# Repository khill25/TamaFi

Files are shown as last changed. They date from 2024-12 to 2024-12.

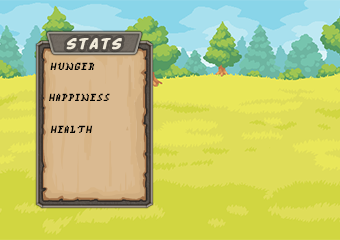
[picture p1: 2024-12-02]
Ui Graphics/pic/backgroundImage.png

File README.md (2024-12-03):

<div align="center">

  
  
  <h1> TamaFi </h1>
  <p> TamaFi is an open-source, WiFi-enabled virtual pet </p>

<!-- Badges -->




<h4>
    <a href="https://twitter.com/techcifer">TWITTER</a>
  <span> · </span>
    <a href="https://www.instagram.com/cifertech/">INSTAGRAM</a>
  <span> · </span>
    <a href="https://www.youtube.com/@techcifer">YOUTUBE</a>
  <span> · </span>
    <a href="https://cifertech.net/">WEBSITE</a>
  </h4>
</div>

<br />

<div>&nbsp;</div>

## 📖 Explore the Full Documentation

Ready to dive deeper into TamaFi's details? Discover the full story, in-depth tutorials, and all the exciting features in our comprehensive [documentation](https://cifertech.net/tamafi-reviving-the-classic-virtual-pet-with-a-tech-twist/). Click the link and explore further!
  
<div>&nbsp;</div>

<!-- About the Project -->
## :star2: About the Project
TamaFi is a modern reimagining of the classic Tamagotchi, aiming to blend nostalgia with modern technology. Built with an ESP32 microcontroller and a vibrant TFT LCD, TamaFi offers a unique twist: feeding your virtual pet through Wi-Fi scanning.

Why TamaFi?
- Classic Tamagotchis lacked vibrant graphics, backlighting, and modern interactions.
- TamaFi fills this gap by offering an enhanced virtual pet experience with open-source versatility.

<div align="center"> 
  
</div>

<div>&nbsp;</div>

<h2>🛠 Functionality Status and Reliability</h2>

TamaFi is a work-in-progress and has room for improvement. While it’s functional and exciting to use, there’s always room to make it better, more reliable, and feature-rich. Whether it’s optimizing the code, enhancing the design, or suggesting new features, your contributions are highly welcomed!

<table>
  <thead>
    <tr>
      <th>Feature</th>
      <th>Status</th>
      <th>Details</th>
    </tr>
  </thead>
  <tbody>
    <tr>
      <td>Pet Animation</td>
      <td>⚠ Stable</td>
      <td>Includes hatching, random, and stat-based animations.</td>
    </tr>
    <tr>
      <td>Stat Management</td>
      <td>⚠ Stable</td>
      <td>Hunger, happiness, and hygiene stats are tracked and updated.</td>
    </tr>
    <tr>
      <td>Wi-Fi Feeding</td>
      <td>🚧 In Progress</td>
      <td>Detects nearby networks and feeds the pet.</td>
    </tr>
    <tr>
      <td>TFT LCD Display</td>
      <td>✅ Reliable</td>
      <td>Displays sprites, stats, and animations with smooth transitions.</td>
    </tr>
    <tr>
      <td>Button Inputs</td>
      <td>⚠ Stable</td>
      <td>Three microswitches handle user interaction.</td>
    </tr>
    <tr>
      <td>PCB Design</td>
      <td>✅ Verified</td>
      <td>Tested for compatibility and efficient layout.</td>
    </tr>
    <tr>
      <td>RGB LED and Buzzer Integration</td>
      <td>🚧 In Progress</td>
      <td>Planned for the next release.</td>
    </tr>
  </tbody>
</table>

<div>&nbsp;</div>

<!-- Features -->
### 🎯 Features

**Hardware:**

- ESP32-U4 microcontroller
- TFT LCD (ST7789) with vibrant visuals
- WS2812 RGB LED for colorful effects
- Buzzer for sound alerts
- TP4056 charging module with USB-C
- LF33 voltage regulator

**Software:**

- Custom animations for pets and stats
- WiFi-based feeding system
- Interactive buttons for actions
- Egg-hatching and pet-death animations
- Open-source and easily customizable

<div>&nbsp;</div>

<!-- License -->
## :warning: License

Distributed under the MIT License. See LICENSE.txt for more information.

<div>&nbsp;</div>

<!-- Contact -->
## :handshake: Contact

▶ Support me on Patreon [patreon.com/cifertech](https://www.patreon.com/cifertech)

CiferTech - [@twitter](https://twitter.com/techcifer) - CiferTech@gmali.com

Project Link: [https://github.com/cifertech/TamaFi](https://github.com/cifertech/TamaFi)

<div>&nbsp;</div>

<!-- Acknowledgments -->
## :gem: Acknowledgements 

**The libraries and projects listed below are used in this software:**
 - [Mecha-Stone Golem](https://darkpixel-kronovi.itch.io/mecha-golem-free)
 - [Fantasy Wooden GUI](https://kanekizlf.itch.io/fantasy-wooden-gui-free)
 - [MyPixelWorld](https://scarloxy.itch.io/mpwsp01)
 - [Transparent Sprites](https://github.com/VolosR/SpritesTuT)

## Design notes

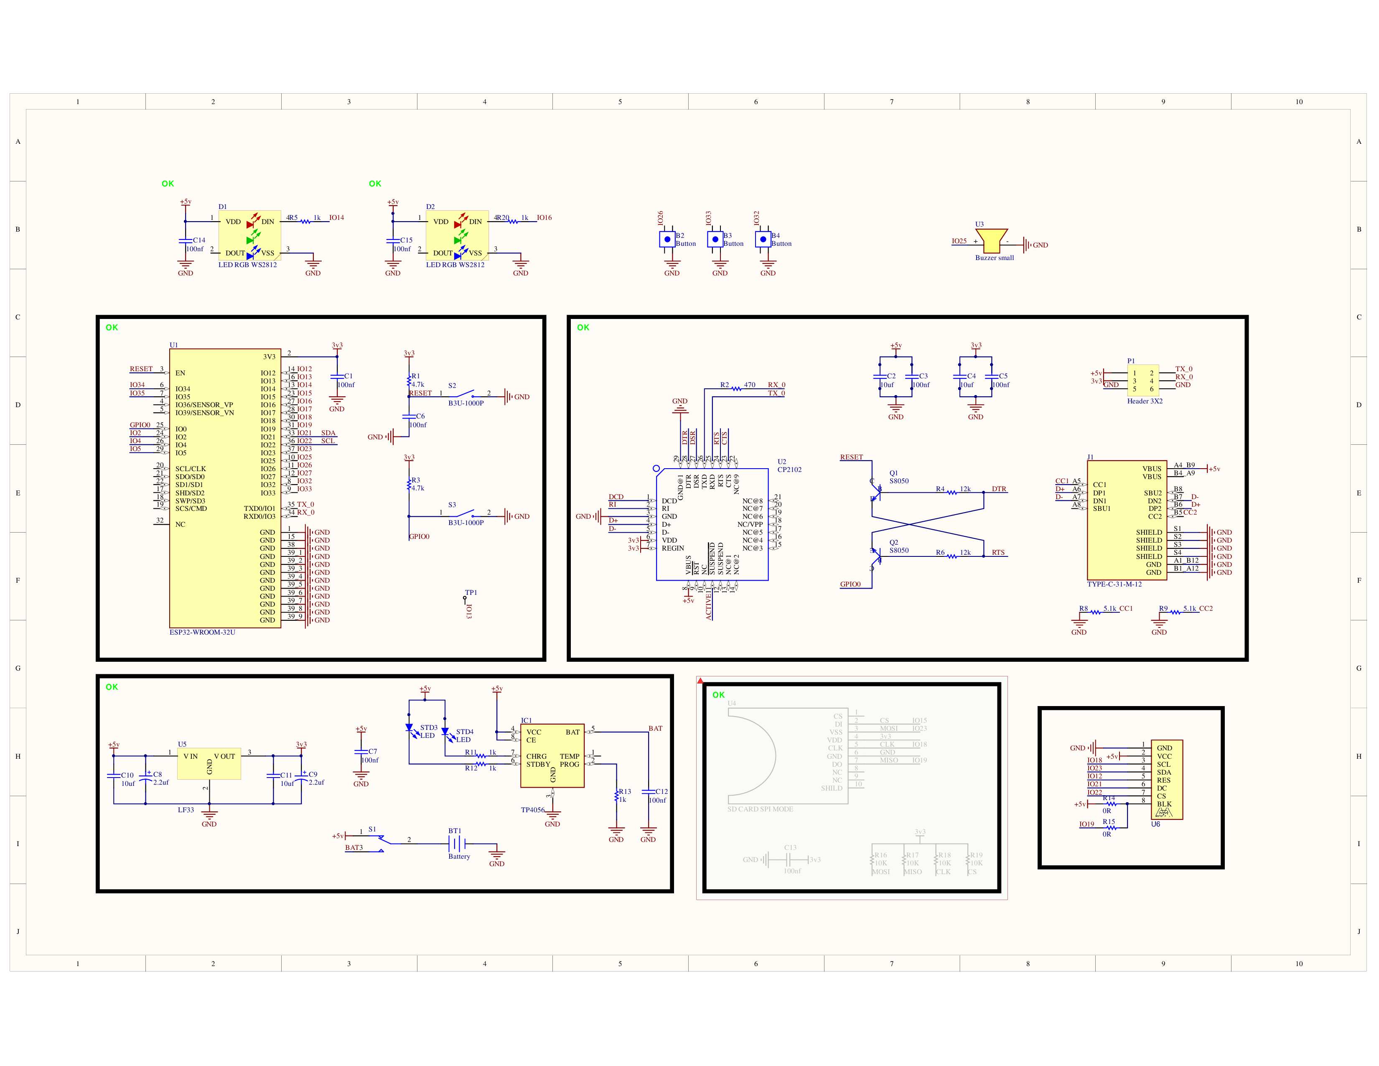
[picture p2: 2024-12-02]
Schematic/schematic.jpg

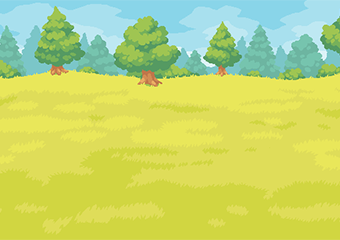
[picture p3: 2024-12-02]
Ui Graphics/pic/backgroundImage1.png

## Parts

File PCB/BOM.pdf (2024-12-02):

Comment | Description | Designator | Footprint | LibRef | Quantity
Button | PUSH BUTTON | B2, B3, B4 | PUSH BUTTON 4 PIN SMD 5 | PUSH BUTTON 4 PIN | 3
Battery | | BT1 | Bat | Battery | 1
100nf | Capacitor | C1, C3, C5, C6, C7, C12, C14, C15 | CAP0805 | CAP SMD | 8
10uf | Capacitor | C2, C4 | CAP0805 | CAP SMD | 2
Capacitor Tantalum SMD | Capacitor Tantalum SMD | C8, C9 | Tan 1206 (3216X18L) Size A | Capacitor Tantalum SMD | 2
10uf | Capacitor | C10, C11 | CAP 1206 (3216X15L) | CAP SMD | 2
LED RGB WS2812 | LED | D1, D2 | LED 5050 WS2812B | LED RGB WS2812 | 2
TP4056 | Complete single cell Li-Ion battery with a constant current / constant voltage linear charger | IC1 | SOP-8 | TP4056 | 1
TYPE-C-31-M-12 | USB Connectors 24 Receptacle 1 8.94*7.3mm RoHS | J1 | HRO_TYPE-C-31-M-12 | TYPE-C-31-M-12 | 1
Header 3X2 | Header, 3-Pin, Dual row | P1 | HDR2X3 | Header 3X2 | 1
S8050 | Bipolar (BJT) Transistor NPN 25 V 500 mA 150MHz 300 mW Surface Mount SOT-23 | Q1, Q2 | SOT-23 | SMD-TRANSISTORS-NPN-25V-500MW(SOT-23) | 2
4.7k | RESISTOR | R1, R3 | RES 0805 | RES | 2
470 | RESISTOR | R2 | RES 0805 | RES | 1
12k | RESISTOR | R4, R6 | RES 0805 | RES | 2
1k | RESISTOR | R5, R20 | RES 0805 (2012X06L) | RES | 2
5.1k | RESISTOR | R8, R9 | RES 0805 | RES | 2
1k | RESISTOR | R11, R12, R13 | RES 0805 | RES | 3
0R | RESISTOR | R14, R15 | RES 0805 | RES | 2
1437566-3 | | S1 | Subminiator SPDT switch | Subminiator SPDT switch | 1
B3U-1000P | Switch Tactile N.O. SPST Round Button Gull Wing 0.05A 12VDC 1.5N SMD Embossed T/R | S2, S3 | SW_B3U-1000P | B3U-1000P | 2
LED | LED | STD3, STD4 | L0805 | LED | 2
Test Point | Test Point | TP1 | Test Point SMD | Test Point | 1
ESP32-WROOM-32U | Bluetooth, WiFi 802.11b/g/n, Bluetooth v4.2 +EDR, Class 1, 2 and 3 Transceiver Module 2.4GHz ~ 2.5GHz Antenna Not Included, U.FL Surface Mount | U1 | XCVR_ESP32-WROOM-32U | ESP32-WROOM-32U | 1
CP2102 | USB Bridge, USB to UART USB 2.0 UART Interface 28-QFN _5x5_ | U2 | QFN28G_0.5-5X5MM | INTERFACE-CP2102-GMR(QFN28) | 1
Buzzer small | 5-12v small buzzer (12mm) | U3 | BUZZER | Buzzer | 1
LF33 | 3.3V VOLTAGE REGULATOR | U5 | D-PACK | LF33 | 1
LCDTFT_1.69IN | LCD TFT Color, 1.69", 240X280, ST7789V Driver | U6 | LCDTFT_1.69IN_ST7 789V_MOD | LCDTFT_1.69IN_ST7 789V_MOD | 1

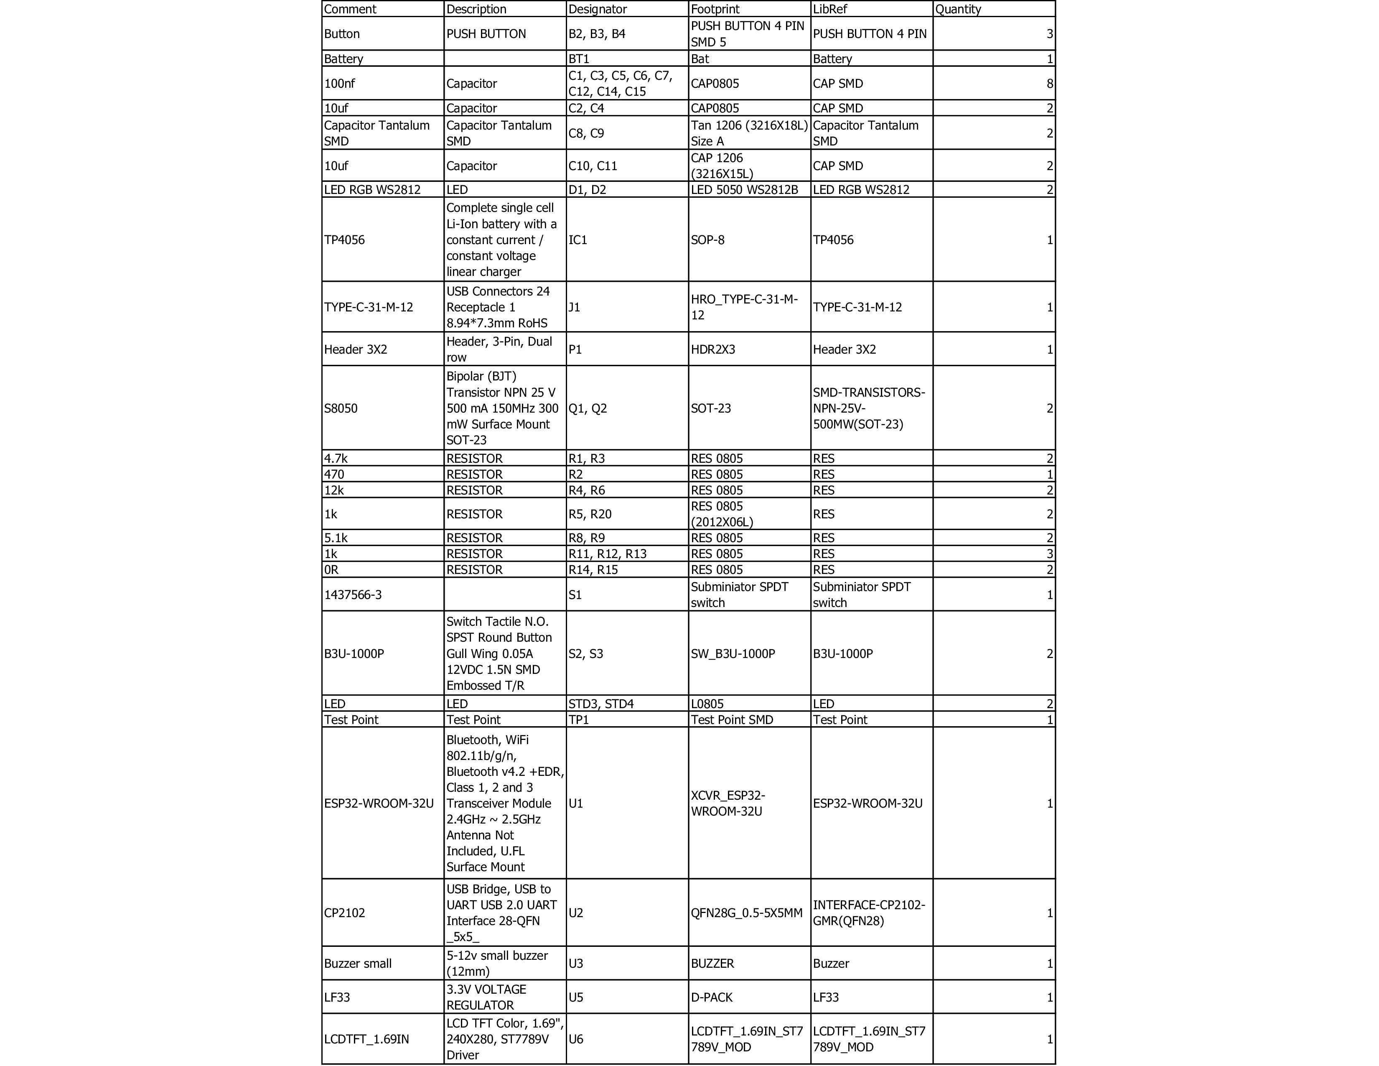
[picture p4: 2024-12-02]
Schematic/components.jpg

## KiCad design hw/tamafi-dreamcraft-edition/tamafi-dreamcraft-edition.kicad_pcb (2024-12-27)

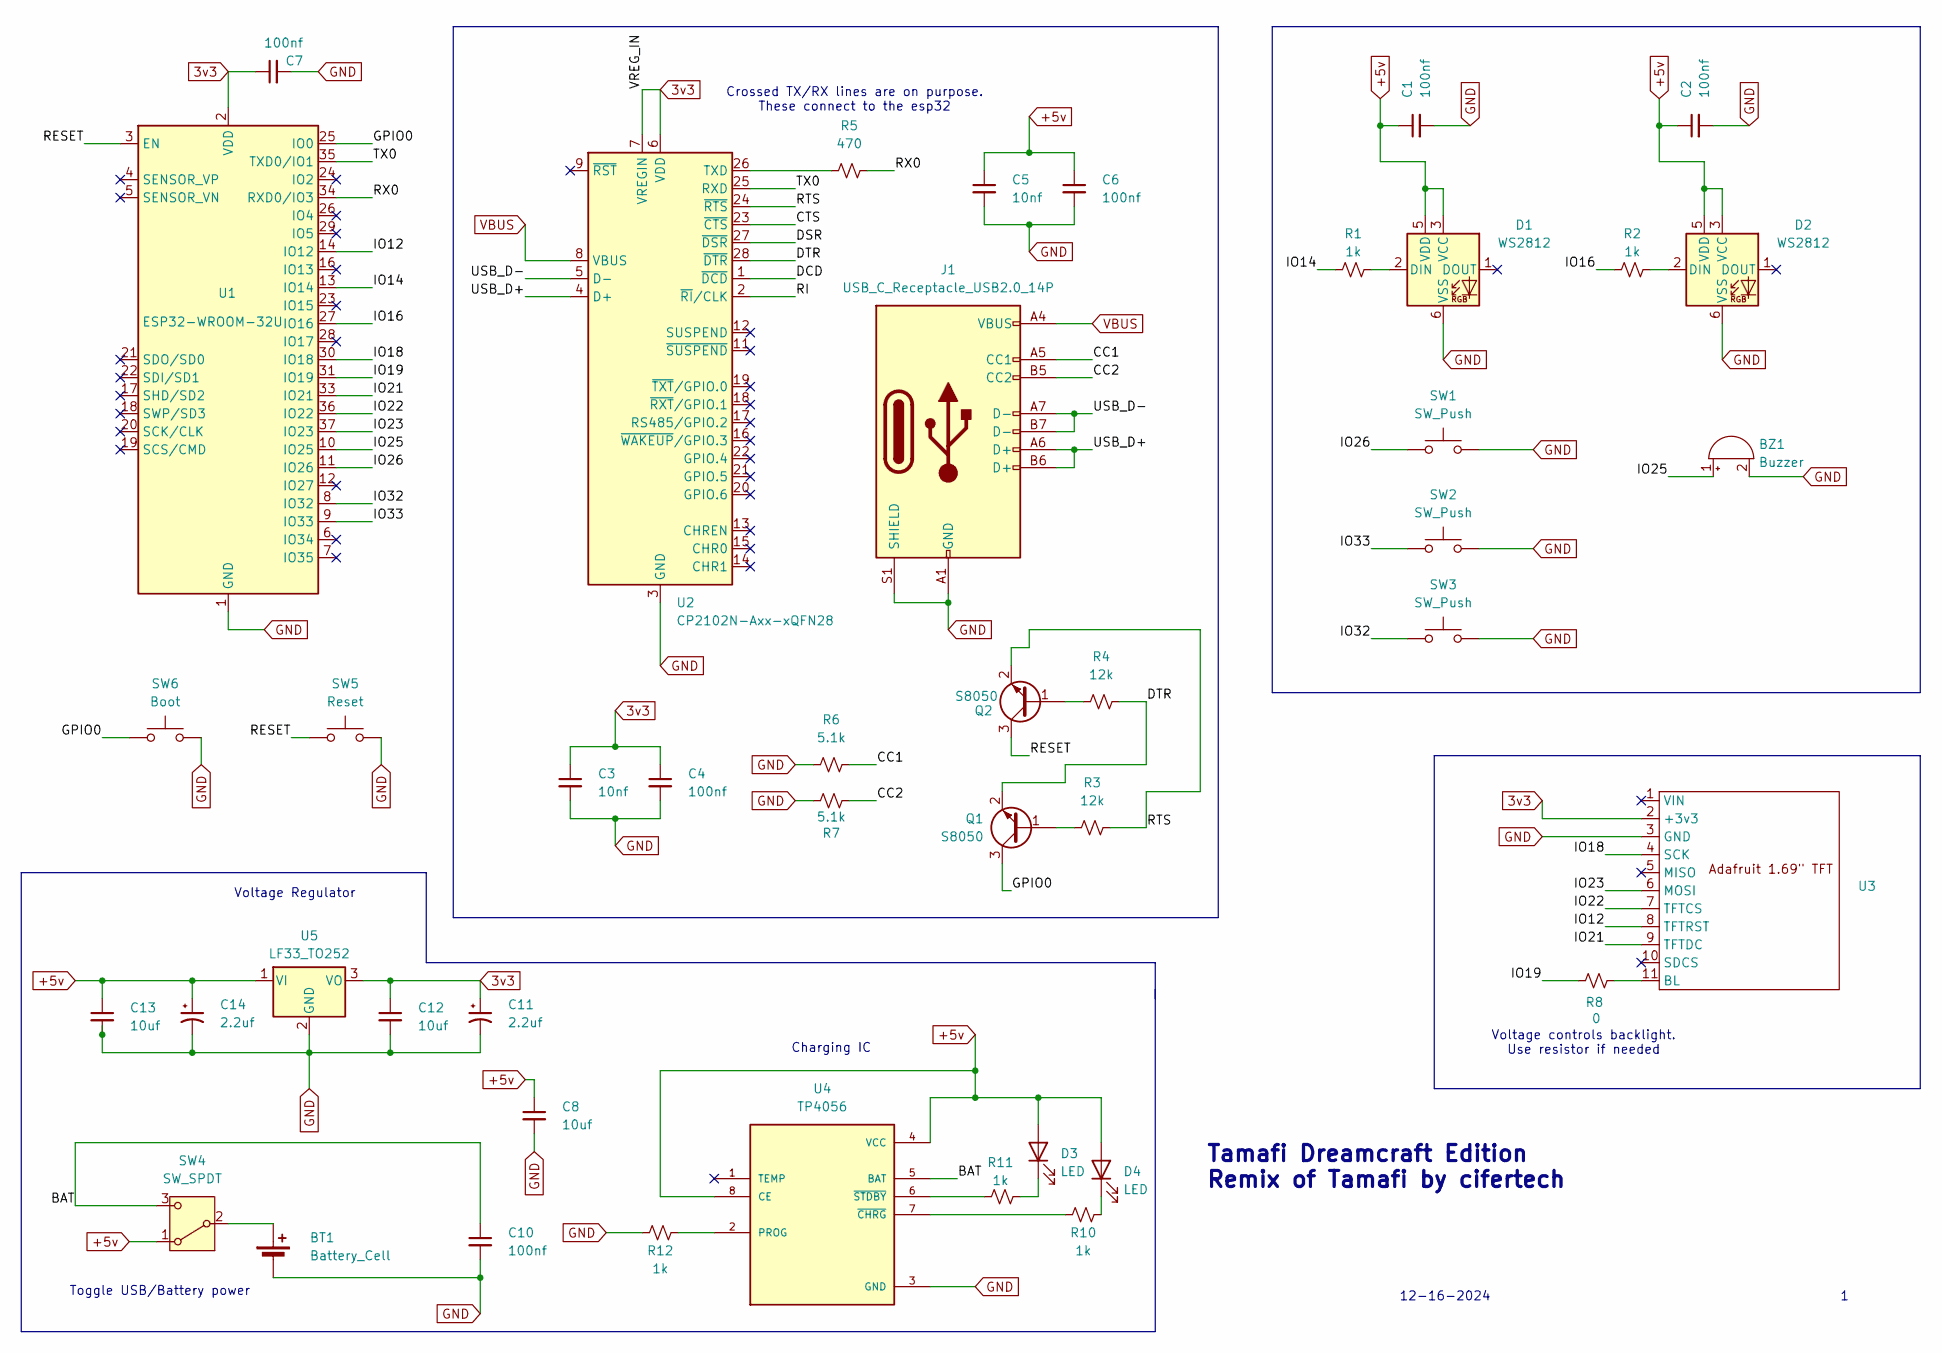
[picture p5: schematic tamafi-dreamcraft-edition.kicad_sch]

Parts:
BT1: Battery_Cell; JST_PH_B2B-PH-K_1x02_P2.00mm_Vertical
BZ1: Buzzer; Buzzer_12x9.5RM7.6
C1, C2, C4, C6, C7, C10: 100nf; C_0805_2012Metric
C3, C5: 10nf; C_0805_2012Metric
C8, C12, C13: 10uf; C_0805_2012Metric
C11, C14: 2.2uf; C_0805_2012Metric
D1, D2: WS2812; LED_WS2812_PLCC6_5.0x5.0mm_P1.6mm
D3, D4: LED; LED_0805_2012Metric_Pad1.15x1.40mm_HandSolder
J1: USB_C_Receptacle_USB2.0_14P; USB_C_Receptacle_HRO_TYPE-C-31-M-12
Q1, Q2: S8050; SOT-23
R1, R2, R10, R11, R12: 1k; R_0805_2012Metric
R3, R4: 12k; R_0805_2012Metric
R5: 470; R_0805_2012Metric
R6, R7: 5.1k; R_0805_2012Metric
R8: 0; R_0805_2012Metric
SW1, SW2, SW3: SW_Push; SW_SPST_B3S-1000
SW4: SW_SPDT; SW_Slide-03_Wuerth-WS-SLTV_10x2.5x6.4_P2.54mm
SW5: Reset; SW_SPST_FSMSM
SW6: Boot; SW_SPST_FSMSM
U1: ESP32-WROOM-32U
U2: CP2102N-Axx-xQFN28; QFN-28-1EP_5x5mm_P0.5mm_EP3.35x3.35mm
U3: Adafruit 1.69in 280x240 TFT
U4: TP4056; SOP-8_3.9x4.9mm_P1.27mm
U5: LF33_TO252; TO-252-2

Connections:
3v3: C3.1, C4.1, C7.1, C11.1, C12.1, U1.2 (VDD), U2.6 (VDD), U2.7 (VREGIN), U3.2 (+3v3), U5.3 (VO)
+5v: C1.1, C2.1, C5.1, C6.1, C8.1, C13.1, C14.1, D1.3 (VCC), D1.5 (VDD), D2.3 (VCC), D2.5 (VDD), D3.2 (A), D4.2 (A), SW4.1 (A), U4.4 (VCC), U4.8 (CE), U5.1 (VI)
/BAT: C10.1, SW4.3 (C), U4.5 (BAT)
/CC1: J1.A5 (CC1), R6.2
/CC2: J1.B5 (CC2), R7.2
/CTS: U2.23 (~CTS)
/DCD: U2.1 (~DCD)
/DSR: U2.27 (~DSR)
/DTR: Q1.2 (E), R4.2, U2.28 (~DTR)
/GPIO0: Q1.3 (C), SW6.1, U1.25 (IO0)
/IO12: U1.14 (IO12), U3.8 (TFTRST)
/IO14: R1.2, U1.13 (IO14)
/IO16: R2.2, U1.27 (IO16)
/IO18: U1.30 (IO18), U3.4 (SCK)
/IO19: R8.2, U1.31 (IO19)
/IO21: U1.33 (IO21), U3.9 (TFTDC)
/IO22: U1.36 (IO22), U3.7 (TFTCS)
/IO23: U1.37 (IO23), U3.6 (MOSI)
/IO25: BZ1.1 (+), U1.10 (IO25)
/IO26: SW1.1, U1.11 (IO26)
/IO32: SW3.1, U1.8 (IO32)
/IO33: SW2.1, U1.9 (IO33)
/RESET: Q2.3 (C), SW5.1, U1.3 (EN)
/RI: U2.2 (~RI/CLK)
/RTS: Q2.2 (E), R3.2, U2.24 (~RTS)
/RX0: R5.2, U1.34 (RXD0/IO3)
/TX0: U1.35 (TXD0/IO1), U2.25 (RXD)
/USB_D+: J1.A6 (D+), J1.B6 (D+), U2.4 (D+)
/USB_D-: J1.A7 (D-), J1.B7 (D-), U2.5 (D-)
GND: BT1.2 (-), BZ1.2 (-), C1.2, C2.2, C3.2, C4.2, C5.2, C6.2, C7.2, C8.2, C10.2, C11.2, C12.2, C13.2, C14.2, D1.6 (VSS), D2.6 (VSS), J1.A1 (GND), J1.A12 (GND), J1.B1 (GND), J1.B12 (GND), J1.S1 (SHIELD), R6.1, R7.1, R12.1, SW1.2, SW2.2, SW3.2, SW5.2, SW6.2, U1.1 (GND), U1.15 (GND), U1.38 (GND), U1.39 (GND), U2.3 (GND), U2.29 (GND), U3.3 (GND), U4.3 (GND), U5.2 (GND)
unnamed: BT1.1 (+), SW4.2 (B)
unnamed: D1.2 (DIN), R1.1
unnamed: D2.2 (DIN), R2.1
unnamed: D3.1 (K), R11.1
unnamed: D4.1 (K), R10.2
unnamed: Q1.1 (B), R3.1
unnamed: Q2.1 (B), R4.1
unnamed: R5.1, U2.26 (TXD)
unnamed: R8.1, U3.11 (BL)
unnamed: R12.2, U4.2 (PROG)
unnamed: R10.1, U4.7 (~CHRG)
unnamed: R11.2, U4.6 (~STDBY)
VBUS: J1.A4 (VBUS), J1.A9 (VBUS), J1.B4 (VBUS), J1.B9 (VBUS), U2.8 (VBUS)

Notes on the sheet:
12-16-2024
Charging IC
Voltage Regulator
Toggle USB/Battery power
Crossed TX/RX lines are on purpose. These connect to the esp32
Voltage controls backlight. Use resistor if needed
Tamafi Dreamcraft Edition Remix of Tamafi by cifertech

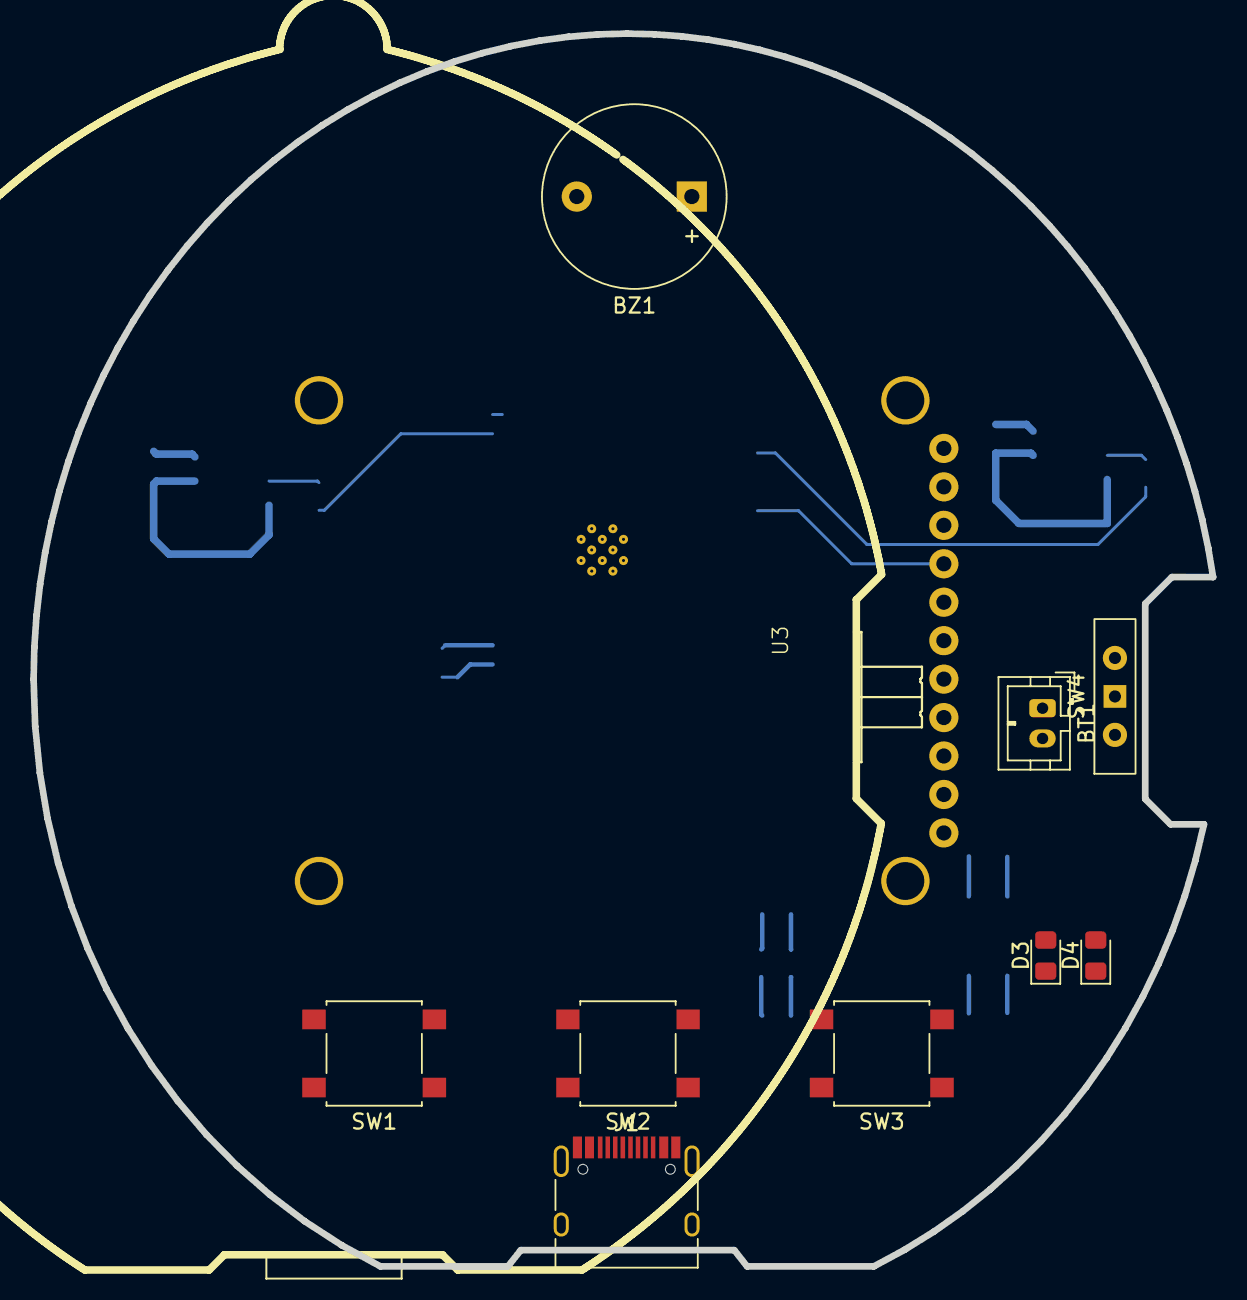
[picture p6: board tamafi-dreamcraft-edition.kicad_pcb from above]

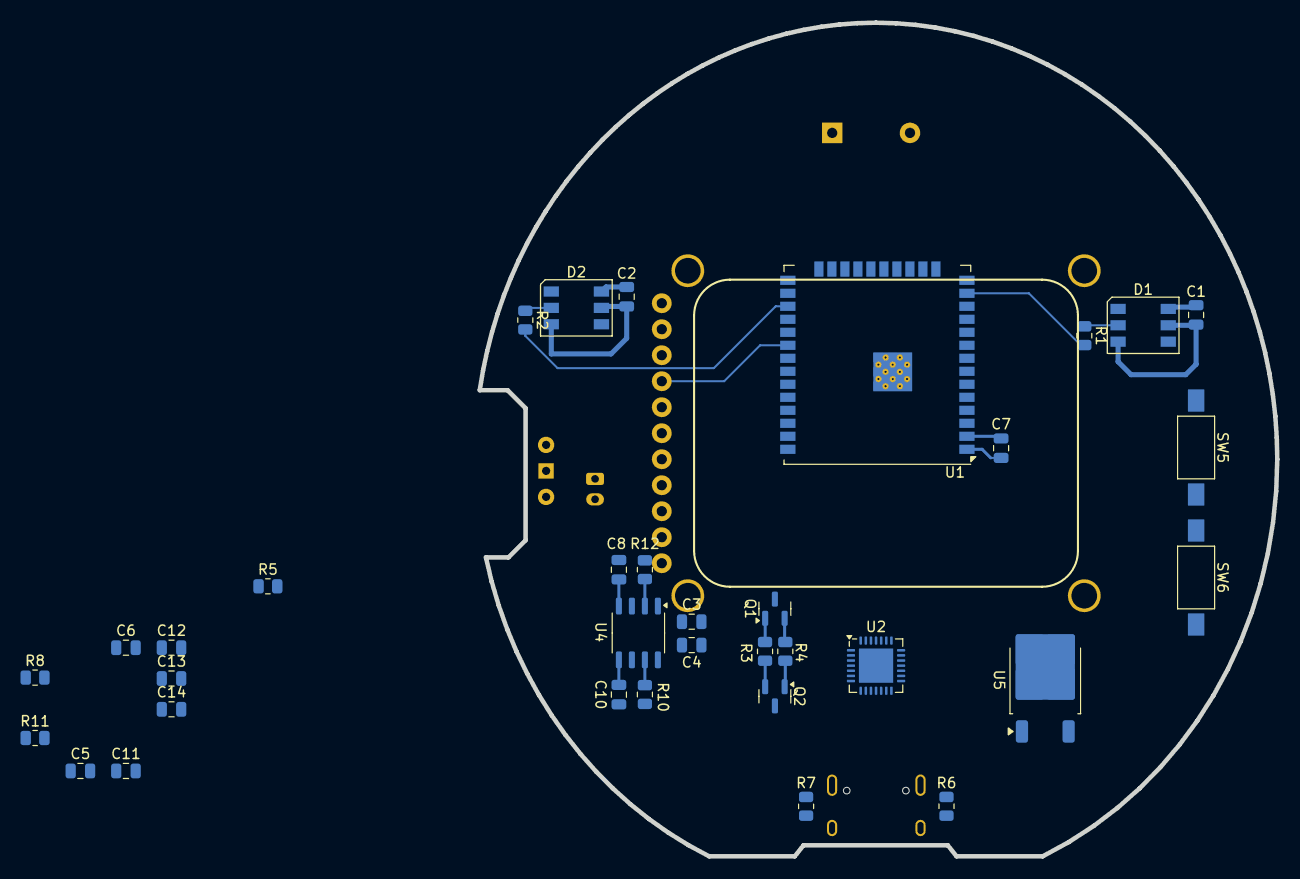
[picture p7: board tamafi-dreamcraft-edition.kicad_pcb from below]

Board: 2 copper layers, 77.9 x 81.4 mm, 44 parts (34 on the bottom side), 39 nets.

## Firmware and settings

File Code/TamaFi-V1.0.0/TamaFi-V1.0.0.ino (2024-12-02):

#include <TFT_eSPI.h>

//#include "pet.h"    
//#include "eyepet.h"  
#include "StoneGolem.h"

#include "egg_hatch.h"
   
#include "effect.h" 
#include "background.h"  

TFT_eSPI tft = TFT_eSPI(); 

TFT_eSprite arrowSprite = TFT_eSprite(&tft); 
TFT_eSprite background = TFT_eSprite(&tft);

TFT_eSprite hatchingSprite = TFT_eSprite(&tft);

bool firstStart = true; // Ensure the animation only runs once

unsigned long lastUpdateTime = 0; // Track the last time logic was updated

// GPIO Button Pins
const int feedButton = 26;
const int playButton = 33;
const int healButton = 32;

// Tamagotchi stats
int hunger = 50;   // 0-100 scale
int happiness = 50; // 0-100 scale
int health = 50;   // 0-100 scale

// Timing variables
unsigned long hungerTimer = 0;
unsigned long happinessTimer = 0;
unsigned long healthTimer = 0;

// Animation frames
int currentFrame = 0; // Animation frame index
const int animationDelay = 200; // Delay between frames
unsigned long lastAnimationTime = 0;

bool hungerEffectActive = false; // Tracks if the hunger animation is active
unsigned long hungerEffectStartTime = 0; // Tracks when the effect starts
int hungerEffectFrame = 0; // Tracks the current frame of the effect


void setup() {
  tft.init();
  tft.setRotation(3);
  tft.setSwapBytes(true);

  background.setColorDepth(8);
  background.createSprite(320, 340);
  background.setSwapBytes(true);

  arrowSprite.createSprite(115, 110);

  // Initialize hatching sprite
  //hatchingSprite.setColorDepth(16);
  hatchingSprite.createSprite(115, 110);
  hatchingSprite.setSwapBytes(false);

  // Initialize the display
  background.fillSprite(TFT_BLACK);
  background.pushSprite(0, 0);



  // Set up buttons as inputs
  pinMode(feedButton, INPUT_PULLUP);
  pinMode(playButton, INPUT_PULLUP);
  pinMode(healButton, INPUT_PULLUP);
}

void loop() {
  unsigned long currentTime = millis();

  // Check button press (assuming hunger button is GPIO 26)
  if (digitalRead(26) == LOW) { // Button is pressed
    if (!hungerEffectActive) {
      hungerEffectActive = true;
      hungerEffectStartTime = millis(); // Record start time
      hungerEffectFrame = 0;            // Reset animation frame
    }
  }

  // Handle hunger effect animation
  if (hungerEffectActive) {
    unsigned long currentTime = millis();
    if (currentTime - hungerEffectStartTime > 100) { // Frame duration: 100ms
      hungerEffectStartTime = currentTime; // Reset frame time
      hungerEffectFrame++;                 // Advance to next frame

      if (hungerEffectFrame >= 4) { // End animation after 4 frames
        hungerEffectActive = false;
      }
    }
  }

  // Render the frame
  renderFrame();

  // Check button presses
  if (digitalRead(feedButton) == LOW) {
    feedPet();
    delay(200); // Debounce delay
  }
  if (digitalRead(playButton) == LOW) {
    playWithPet();
    delay(200); // Debounce delay
  }
  if (digitalRead(healButton) == LOW) {
    healPet();
    delay(200); // Debounce delay
  }

  // Update Tamagotchi stats every 5 seconds
  if (currentTime - hungerTimer >= 5000) {
    hunger = max(0, hunger - 5); // Decrease hunger
    hungerTimer = currentTime;
  }
  if (currentTime - happinessTimer >= 7000) {
    happiness = max(0, happiness - 3); // Decrease happiness
    happinessTimer = currentTime;
  }
  if (currentTime - healthTimer >= 10000) {
    health = max(0, health - 1); // Decrease health
    healthTimer = currentTime;
  }

  // Animation Logic
  if (currentTime - lastAnimationTime >= animationDelay) {
    currentFrame = (currentFrame + 1) % 4; // Loop through frames 0-3
    lastAnimationTime = currentTime;

    // Render the current frame
    renderFrame();
  }

  // Check if stats fall too low
  if (hunger <= 0 && happiness <= 0 && health <= 0) {
    displayGameOver();
    //return; // End the loop
  }

  if (firstStart) {
    playHatchingAnimationLoop(); // Run the hatching animation
    firstStart = false;          // Mark animation as done
    hatchingSprite.deleteSprite(); // Free memory after animation
  }
}

void playHatchingAnimationLoop() {
  int delayTime = 300; // Delay between frames

    // Frame 1
    background.pushImage(0, 0, 340, 240, backgroundImage2);
    hatchingSprite.pushImage(0, 0, 115, 110, egg_hatch_1);
    hatchingSprite.pushToSprite(&background, 100, 90, TFT_WHITE); // Adjust position
    background.pushSprite(0, 0);
    delay(delayTime);

    // Frame 2
    background.pushImage(0, 0, 340, 240, backgroundImage2);
    hatchingSprite.pushImage(0, 0, 115, 110, egg_hatch_2);
    hatchingSprite.pushToSprite(&background, 100, 90, TFT_WHITE);
    background.pushSprite(0, 0);
    delay(delayTime);

    // Frame 3
    background.pushImage(0, 0, 340, 240, backgroundImage2);
    hatchingSprite.pushImage(0, 0, 115, 110, egg_hatch_3);
    hatchingSprite.pushToSprite(&background, 100, 90, TFT_WHITE);
    background.pushSprite(0, 0);
    delay(delayTime);

    // Frame 4
    background.pushImage(0, 0, 340, 240, backgroundImage2);
    hatchingSprite.pushImage(0, 0, 115, 110, egg_hatch_4);
    hatchingSprite.pushToSprite(&background, 100, 90, TFT_WHITE);
    background.pushSprite(0, 0);
    delay(delayTime);

    // Frame 5
    background.pushImage(0, 0, 340, 240, backgroundImage2);
    hatchingSprite.pushImage(0, 0, 115, 110, egg_hatch_5);
    hatchingSprite.pushToSprite(&background, 100, 90, TFT_WHITE);
    background.pushSprite(0, 0);
    delay(delayTime); 
       
  while (digitalRead(26) == HIGH) { // Wait until button is pressed
    // Cracking Frame
    background.pushImage(0, 0, 340, 240, backgroundImage2);
    hatchingSprite.pushImage(0, 0, 115, 110, idle_1);
    hatchingSprite.pushToSprite(&background, 100, 90, TFT_WHITE);
    background.pushSprite(0, 0);
    delay(delayTime);
  }
}


void renderFrame() {
  background.pushImage(0, 0, 340, 240, backgroundImage); // Draw the background image
  arrowSprite.setSwapBytes(false); 
  
  // Draw the regular pet animation
  switch (currentFrame) {
    case 0:
      arrowSprite.pushImage(0, 0, 115, 110, idle_1);
      break;
    case 1:
      arrowSprite.pushImage(0, 0, 115, 110, idle_2);
      break;
    case 2:
      arrowSprite.pushImage(0, 0, 115, 110, idle_3);
      break;
    case 3:
      arrowSprite.pushImage(0, 0, 115, 110, idle_4);
      break;
  }

  arrowSprite.pushToSprite(&background, 180, 80, TFT_WHITE); // Place the pet on the background

  // If the hunger effect is active, overlay the effect animation on top of the pet
  if (hungerEffectActive) {
    TFT_eSprite effectSprite = TFT_eSprite(&tft);  // Temporary sprite for the effect
    effectSprite.createSprite(100, 95);            // Match the pet sprite size
    effectSprite.setSwapBytes(false);              // Enable 8-bit color depth if needed

    switch (hungerEffectFrame) {
      case 0:
        effectSprite.pushImage(0, 0, 100, 96, hunger1);
        break;
      case 1:
        effectSprite.pushImage(0, 0, 100, 95, hunger2);
        break;
      case 2:
        effectSprite.pushImage(0, 0, 100, 95, hunger3);
        break;
      case 3:
        effectSprite.pushImage(0, 0, 100, 95, hunger4);
        break;
    }

    effectSprite.pushToSprite(&background, 180, 80, TFT_WHITE); // Overlay effect on top of the pet
    effectSprite.deleteSprite(); // Clean up temporary sprite
  }

  drawStats(); // Render stat bars
  background.pushSprite(0, 0); // Push everything to the display
}

void drawStats() {
  // Define bar properties
  int barWidth = 80;     // Width of stat bars
  int barHeight = 8;     // Height of stat bars
  int barX = 50;         // X-coordinate for all bars
  int hungerY = 73;      // Y-coordinate for hunger bar
  int happinessY = 105;  // Y-coordinate for happiness bar
  int healthY = 137;     // Y-coordinate for health bar

  // Draw Hunger bar
  background.fillRect(barX, hungerY, barWidth, barHeight, TFT_DARKGREY); // Background bar
  background.fillRect(barX, hungerY, hunger, barHeight, TFT_RED);        // Filled portion

  // Draw Happiness bar
  background.fillRect(barX, happinessY, barWidth, barHeight, TFT_DARKGREY); // Background bar
  background.fillRect(barX, happinessY, happiness, barHeight, TFT_YELLOW);  // Filled portion

  // Draw Health bar
  background.fillRect(barX, healthY, barWidth, barHeight, TFT_DARKGREY); // Background bar
  background.fillRect(barX, healthY, health, barHeight, TFT_GREEN);      // Filled portion
}

// Actions triggered by buttons
void feedPet() {
  hunger = min(80, hunger + 20);
}

void playWithPet() {
  happiness = min(80, happiness + 20);
}

void healPet() {
  health = min(80, health + 20);
}

void displayGameOver() {

        // Display the frames of the dying animation
        background.pushImage(0, 0, 340, 240, backgroundImage);
        arrowSprite.pushImage(0, 0, 115, 110, dead_1);
        arrowSprite.pushToSprite(&background, 180, 80, TFT_WHITE);
        background.pushSprite(0, 0);
        delay(300);

        background.pushImage(0, 0, 340, 240, backgroundImage);
        arrowSprite.pushImage(0, 0, 115, 110, dead_2);
        arrowSprite.pushToSprite(&background, 180, 80, TFT_WHITE);
        background.pushSprite(0, 0);
        delay(300);

        while (digitalRead(26) == HIGH) {

        background.pushImage(0, 0, 340, 240, backgroundImage);
        arrowSprite.pushImage(0, 0, 115, 110, dead_3);
        arrowSprite.pushToSprite(&background, 180, 80, TFT_WHITE);
        background.pushSprite(0, 0);
        delay(300);
        
  }
}
